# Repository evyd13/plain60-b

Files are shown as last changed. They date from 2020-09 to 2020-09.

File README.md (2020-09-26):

# Plain60-B

Plain60-B PCB
This universal 60% PCB is designed to support as little layouts as possible without limiting usability for most users. The reason I did this is because other PCBs made for this form factor usually have so many supported layouts that it could almost qualify as swiss cheese.

It also features a fuse and an ESD protection chip to protect the MCU and other parts of the PCB.

## Features
- QMK Firmware
- Compatible with most universal 60% cases
- Mini USB
- ESD protection and fuse
- No LEDs and no underglow
- Minimal layout support
- ISP header

## Supported layouts
Supported layouts of the Plain60-B

## Building
If you feel like building a few of these PCBs yourself, go to the 'Releases' tab and download the latest gerber files. Order those at your favourite PCB manufacturer, get the components needed (see below) and solder them on! A hot air station is not required but a soldering iron is. Flux is recommended.

## Opening the project
To open the files you will need the latest KiCAD nightly version.

## Bill of materials (BOM)
Amount is per PCB, multiply as needed.

| LCSC part # | Description | Value | Package  | Amount |
| --- | --- | ----- | --- | ---:|
| C296091 | Capacitor | 22pF  | 0805 | 2 |
| C128353 | Capacitor | 0.1uF | 0805 | 4 |
| C131056 | Capacitor | 4.7uF | 0805 | 1 |
| C215803 | Capacitor | 1uF | 0805 | 1 |
| C109001 | Diode | | 0805 | 65 |
| C261942 | Fuse | | 0805 | 1 |
| C145778 | Connector | | SMD/THT  | 1 |
| C103904 | Resistor | 10K | 0805 | 2 |
| C325772 | Resistor | 22 | 0805 | 2 |
| C44854 | MCU | 32U4  | QFP-44 | 1 |
| C7519 | ESD chip | | SOT23-6  | 1 |
| C255909 | Crystal | 16MHz | TSX-3225 | 1 |
| C92584 | Switch | | SMD | 1 |

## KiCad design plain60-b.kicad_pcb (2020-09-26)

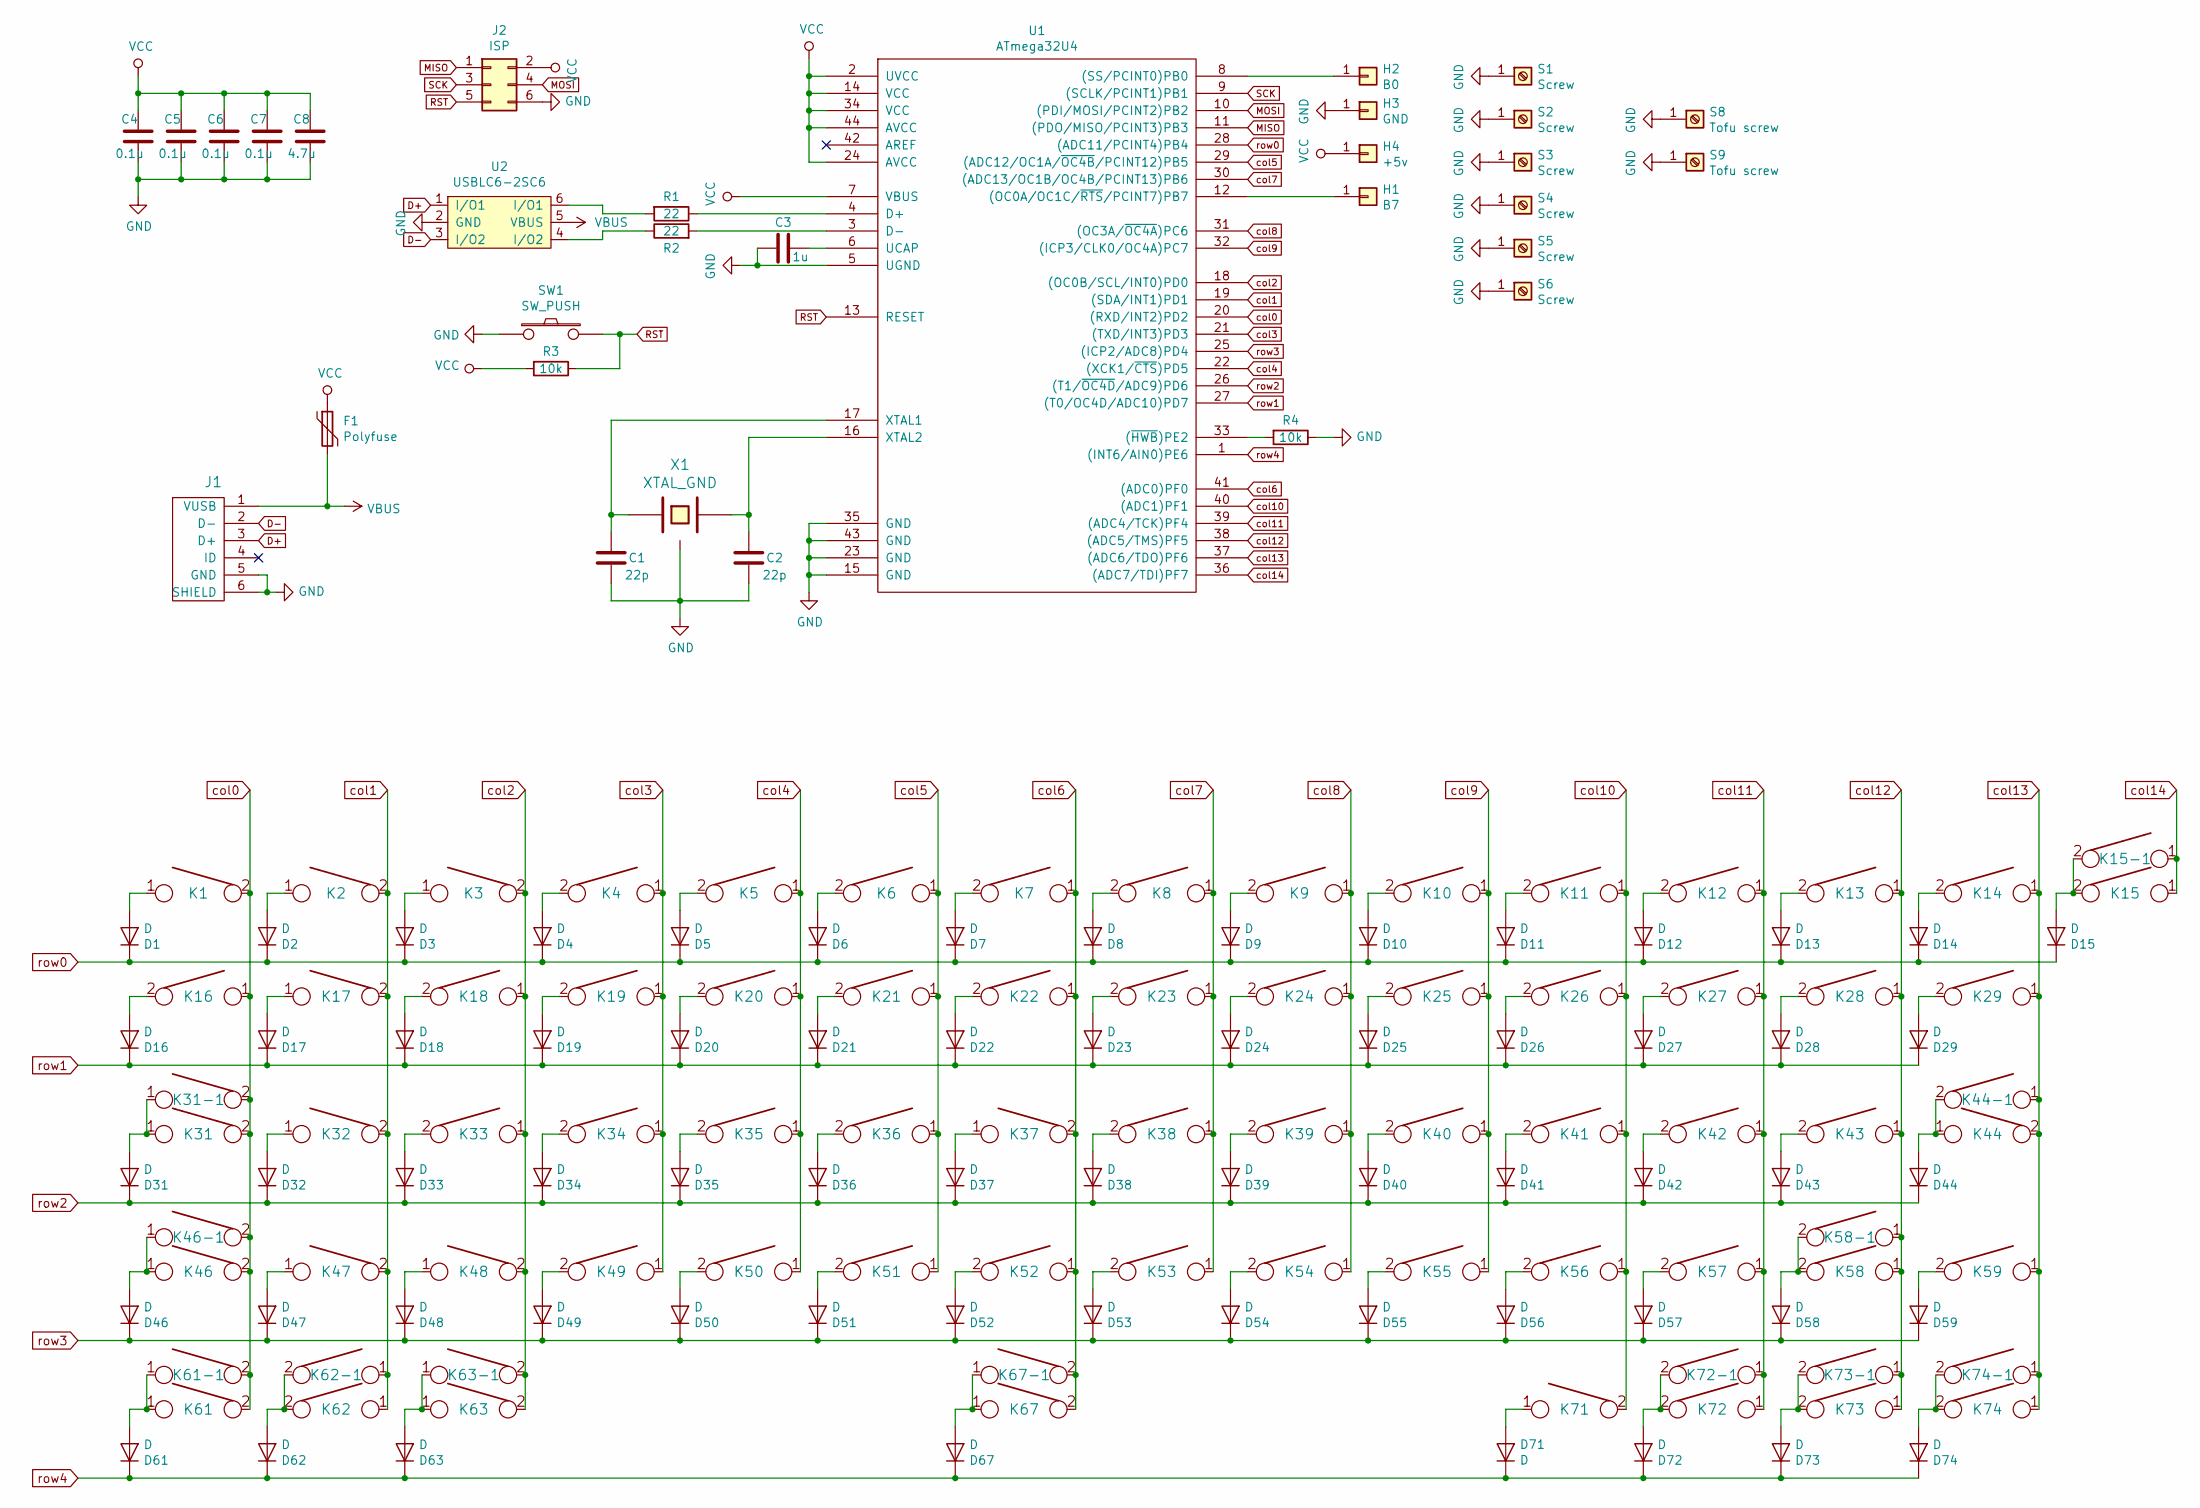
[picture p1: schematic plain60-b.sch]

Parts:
C1, C2: 22p; C_0805
C3: 1u; C_0805
C4, C5, C6, C7: 0.1u; C_0805
C8: 4.7u; C_0805
D1, D2, D3, D4, D5, D6, D7, D8, D9, D10, D11, D12, D13, D14, D15, D16, D17, D18, D19, D20, D21, D22, D23, D24, D25, D26, D27, D28, D29, D31, D32, D33, D34, D35, D36, D37, D38, D39, D40, D41, D42, D43, D44, D46, D47, D48, D49, D50, D51, D52, D53, D54, D55, D56, D57, D58, D59, D61, D62, D63, D67, D71, D72, D73, D74: D; D_0805
F1: Polyfuse; R_0805
H1: B7; free_pin
H2: B0; free_pin
H3: GND; free_pin
H4: +5v; free_pin
J1: USB_mini_micro_B; U-M-M5DD-W-1
J2: ISP; isp_standard
K1, K2, K3, K4, K5, K6, K7, K8, K9, K10, K11, K12, K13, K14, K15-1, K17, K18, K19, K20, K21, K22, K23, K24, K25, K26, K27, K28, K32, K33, K34, K35, K36, K37, K38, K39, K40, K41, K42, K43, K47, K48, K49, K50, K51, K52, K53, K54, K55, K56, K57, K59, K62-1, K73-1: KEYSW; CHERRY_PLATE_100H
K15: KEYSW; CHERRY_PCB_200H
K16, K29, K61-1, K63-1, K72-1, K74-1: KEYSW; CHERRY_PLATE_150H
K31, K58-1: KEYSW; CHERRY_PLATE_175H
K31-1, K46-1, K61, K62, K63, K71, K72, K73, K74: KEYSW; CHERRY_PLATE_125H
K44, K46: KEYSW; CHERRY_PCB_225H
K44-1: KEYSW; CHERRY_PCB_200H_V
K58: KEYSW; CHERRY_PCB_275H
K67: KEYSW; CHERRY_PCB_625H_F
K67-1: KEYSW; CHERRY_PCB_700H_F
R1, R2: 22; R_0805
R3, R4: 10k; R_0805
S1, S2, S3, S6: Screw; 5.5_5x2.5mm
S4, S5: Screw; 10x5_7x2.5mm
S8, S9: Tofu screw; 5.5_5x2.5mm
SW1: SW_PUSH; SW_SPST_TL3342
U1: ATmega32U4; ATMEGA32U4
U2: USBLC6-2SC6; Farnell 1295310
X1: XTAL_GND; crystal_FA238-TSX3225

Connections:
D+: J1.3 (D+), U2.1 (I/O1)
D-: J1.2 (D-), U2.3 (I/O2)
GND: C1.1, C2.1, C3.2, C4.1, C5.1, C6.1, C7.1, C8.1, H3.1, J1.5 (GND), J1.6 (SHIELD), J2.6, R4.1, S1.1, S2.1, S3.1, S4.1, S5.1, S6.1, S8.1, S9.1, SW1.1, U1.5 (UGND), U1.15 (GND), U1.23 (GND), U1.35 (GND), U1.43 (GND), U2.2 (GND), X1.3
MISO: J2.1, U1.11 ((PDO/MISO/PCINT3)PB3)
MOSI: J2.4, U1.10 ((PDI/MOSI/PCINT2)PB2)
unnamed: C1.2, U1.17 (XTAL1), X1.1
unnamed: C2.2, U1.16 (XTAL2), X1.2
unnamed: C3.1, U1.6 (UCAP)
unnamed: D1.2 (A), K1.1
unnamed: D2.2 (A), K2.1
unnamed: D3.2 (A), K3.1
unnamed: D4.2 (A), K4.2
unnamed: D5.2 (A), K5.2
unnamed: D6.2 (A), K6.2
unnamed: D7.2 (A), K7.2
unnamed: D8.2 (A), K8.2
unnamed: D9.2 (A), K9.2
unnamed: D10.2 (A), K10.2
unnamed: D11.2 (A), K11.2
unnamed: D12.2 (A), K12.2
unnamed: D13.2 (A), K13.2
unnamed: D14.2 (A), K14.2
unnamed: D15.2 (A), K15.2, K15-1.2
unnamed: D16.2 (A), K16.2
unnamed: D17.2 (A), K17.1
unnamed: D18.2 (A), K18.2
unnamed: D19.2 (A), K19.2
unnamed: D20.2 (A), K20.2
unnamed: D21.2 (A), K21.2
unnamed: D22.2 (A), K22.2
unnamed: D23.2 (A), K23.2
unnamed: D24.2 (A), K24.2
unnamed: D25.2 (A), K25.2
unnamed: D26.2 (A), K26.2
unnamed: D27.2 (A), K27.2
unnamed: D28.2 (A), K28.2
unnamed: D29.2 (A), K29.2
unnamed: D31.2 (A), K31.1, K31-1.1
unnamed: D32.2 (A), K32.1
unnamed: D33.2 (A), K33.2
unnamed: D34.2 (A), K34.2
unnamed: D35.2 (A), K35.2
unnamed: D36.2 (A), K36.2
unnamed: D37.2 (A), K37.1
unnamed: D38.2 (A), K38.2
unnamed: D39.2 (A), K39.2
unnamed: D40.2 (A), K40.2
unnamed: D41.2 (A), K41.2
unnamed: D42.2 (A), K42.2
unnamed: D43.2 (A), K43.2
unnamed: D44.2 (A), K44.1, K44-1.2
unnamed: D46.2 (A), K46.1, K46-1.1
unnamed: D47.2 (A), K47.1
unnamed: D48.2 (A), K48.1
unnamed: D49.2 (A), K49.2
unnamed: D50.2 (A), K50.2
unnamed: D51.2 (A), K51.2
unnamed: D52.2 (A), K52.2
unnamed: D53.2 (A), K53.2
unnamed: D54.2 (A), K54.2
unnamed: D55.2 (A), K55.2
unnamed: D56.2 (A), K56.2
unnamed: D57.2 (A), K57.2
unnamed: D58.2 (A), K58.2, K58-1.2
unnamed: D59.2 (A), K59.2
unnamed: D61.2 (A), K61.1, K61-1.1
unnamed: D62.2 (A), K62.2, K62-1.2
unnamed: D63.2 (A), K63.1, K63-1.1
unnamed: D67.2 (A), K67.1, K67-1.1
unnamed: D71.2 (A), K71.1
unnamed: D72.2 (A), K72.2, K72-1.2
unnamed: D73.2 (A), K73.2, K73-1.2
unnamed: D74.2 (A), K74.2, K74-1.2
unnamed: H1.1, U1.12 ((OC0A/OC1C/~RTS~/PCINT7)PB7)
unnamed: H2.1, U1.8 ((SS/PCINT0)PB0)
unnamed: R1.1, U1.4 (D+)
unnamed: R1.2, U2.6 (I/O1)
unnamed: R2.1, U2.4 (I/O2)
unnamed: R2.2, U1.3 (D-)
unnamed: R4.2, U1.33 ((~HWB~)PE2)
RST: J2.5, R3.1, SW1.2, U1.13 (RESET)
SCK: J2.3, U1.9 ((SCLK/PCINT1)PB1)
VBUS: F1.2, J1.1 (VUSB), U2.5 (VBUS)
VCC: C4.2, C5.2, C6.2, C7.2, C8.2, F1.1, H4.1, J2.2, R3.2, U1.2 (UVCC), U1.7 (VBUS), U1.14 (VCC), U1.24 (AVCC), U1.34 (VCC), U1.44 (AVCC)
col0: K1.2, K16.1, K31.2, K31-1.2, K46.2, K46-1.2, K61.2, K61-1.2, U1.20 ((RXD/INT2)PD2)
col1: K2.2, K17.2, K32.2, K47.2, K62.1, K62-1.1, U1.19 ((SDA/INT1)PD1)
col2: K3.2, K18.1, K33.1, K48.2, K63.2, K63-1.2, U1.18 ((OC0B/SCL/INT0)PD0)
col3: K4.1, K19.1, K34.1, K49.1, U1.21 ((TXD/INT3)PD3)
col4: K5.1, K20.1, K35.1, K50.1, U1.22 ((XCK1/~CTS~)PD5)
col5: K6.1, K21.1, K36.1, K51.1, U1.29 ((ADC12/OC1A/~OC4B~/PCINT12)PB5)
col6: K7.1, K22.1, K37.2, K52.1, K67.2, K67-1.2, U1.41 ((ADC0)PF0)
col7: K8.1, K23.1, K38.1, K53.1, U1.30 ((ADC13/OC1B/OC4B/PCINT13)PB6)
col8: K9.1, K24.1, K39.1, K54.1, U1.31 ((OC3A/~OC4A~)PC6)
col9: K10.1, K25.1, K40.1, K55.1, U1.32 ((ICP3/CLK0/OC4A)PC7)
col10: K11.1, K26.1, K41.1, K56.1, K71.2, U1.40 ((ADC1)PF1)
col11: K12.1, K27.1, K42.1, K57.1, K72.1, K72-1.1, U1.39 ((ADC4/TCK)PF4)
col12: K13.1, K28.1, K43.1, K58.1, K58-1.1, K73.1, K73-1.1, U1.38 ((ADC5/TMS)PF5)
col13: K14.1, K29.1, K44.2, K44-1.1, K59.1, K74.1, K74-1.1, U1.37 ((ADC6/TDO)PF6)
col14: K15.1, K15-1.1, U1.36 ((ADC7/TDI)PF7)
row0: D1.1 (K), D2.1 (K), D3.1 (K), D4.1 (K), D5.1 (K), D6.1 (K), D7.1 (K), D8.1 (K), D9.1 (K), D10.1 (K), D11.1 (K), D12.1 (K), D13.1 (K), D14.1 (K), D15.1 (K), U1.28 ((ADC11/PCINT4)PB4)
row1: D16.1 (K), D17.1 (K), D18.1 (K), D19.1 (K), D20.1 (K), D21.1 (K), D22.1 (K), D23.1 (K), D24.1 (K), D25.1 (K), D26.1 (K), D27.1 (K), D28.1 (K), D29.1 (K), U1.27 ((T0/OC4D/ADC10)PD7)
row2: D31.1 (K), D32.1 (K), D33.1 (K), D34.1 (K), D35.1 (K), D36.1 (K), D37.1 (K), D38.1 (K), D39.1 (K), D40.1 (K), D41.1 (K), D42.1 (K), D43.1 (K), D44.1 (K), U1.26 ((T1/~OC4D~/ADC9)PD6)
row3: D46.1 (K), D47.1 (K), D48.1 (K), D49.1 (K), D50.1 (K), D51.1 (K), D52.1 (K), D53.1 (K), D54.1 (K), D55.1 (K), D56.1 (K), D57.1 (K), D58.1 (K), D59.1 (K), U1.25 ((ICP2/ADC8)PD4)
row4: D61.1 (K), D62.1 (K), D63.1 (K), D67.1 (K), D71.1 (K), D72.1 (K), D73.1 (K), D74.1 (K), U1.1 ((INT6/AIN0)PE6)

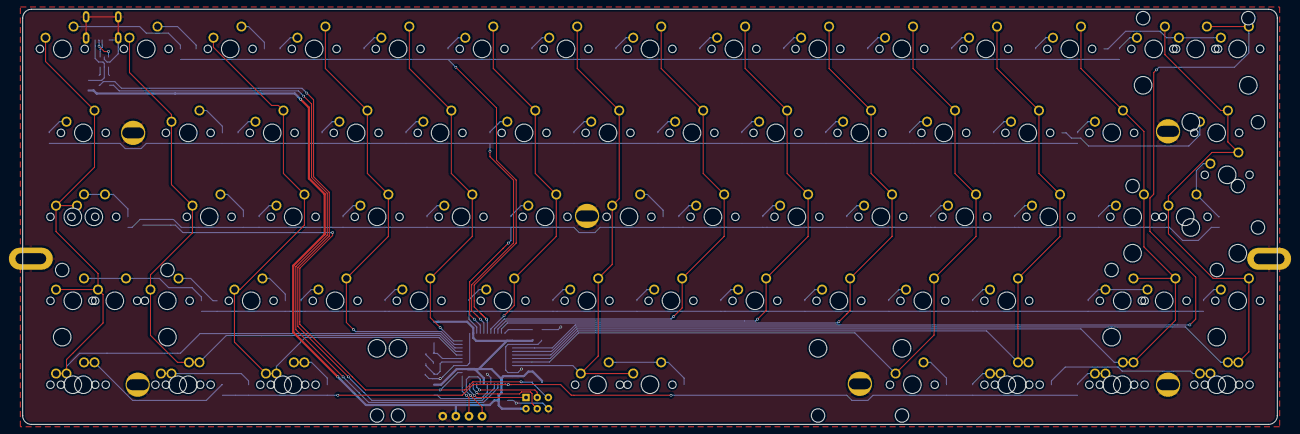
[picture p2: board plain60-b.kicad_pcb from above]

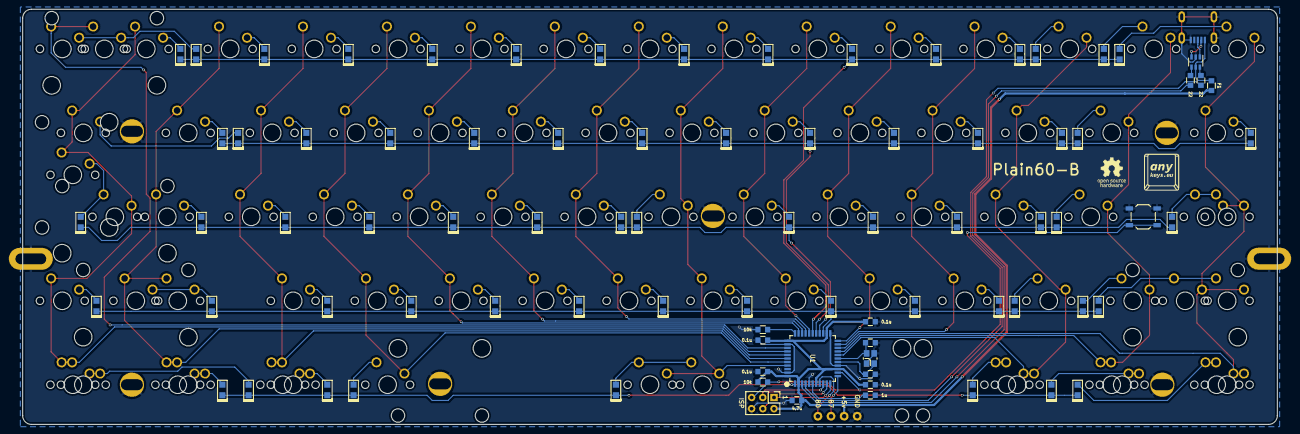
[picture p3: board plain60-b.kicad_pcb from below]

Board: 2 copper layers, 284.7 x 94.2 mm, 173 parts (88 on the bottom side), 104 nets.

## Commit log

2019-04-07 First upload
    [plain60-b.dsn, plain60-b.kicad_pcb, plain60-b.sch]
2019-04-07 Update PCB and readme picture
    [plain60-b.kicad_pcb]
2020-09-26 Change website logo
    [plain60-b.kicad_pcb]
